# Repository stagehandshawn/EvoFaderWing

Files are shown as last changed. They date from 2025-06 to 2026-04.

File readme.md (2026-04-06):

# EvoFaderWing - [Wiki](https://github.com/stagehandshawn/EvoFaderWing/wiki)

<table width="100%">
  <tr>
    <td width="70%">
      <table width="100%">
        <tr>
          <td align="left">
            <strong>Author:</strong> ShawnR
          </td>
          <td align="right">
            <strong>Contact:</strong> <a href="mailto:stagehandshawn@gmail.com">stagehandshawn@gmail.com</a>
          </td>
        </tr>
      </table>
      <br>
      OSC control of grandMA3 faders with motorized feedback, backlit faders (follows appearances), 20 encoders, and 40 standard exec buttons.
      <br><br><blockquote>
        <strong>Note:</strong> This Guide is a work in progress but EvoFaderWing is fully functional. I continue to work on the repo as time permits.
      </blockquote>
    </td>
    <td width="30%" align="right" valign="top">
      faderwing
    </td>
  </tr>
</table>

[Bill Of Materials](https://github.com/stagehandshawn/EvoFaderWing/wiki/Bill-of-materials)

[Wiring Diagrams](https://github.com/stagehandshawn/EvoFaderWing/wiki/Wiring-Diagrams)

[Assembly](https://github.com/stagehandshawn/EvoFaderWing/wiki/Assembly)

I have added discussions to the repo so any questions can be asked there. 

## Features
### Same quantity of control surfaces as grandMA3 onPC Fader Wing
- 10 Motorized faders
  - Touch sensitive
  - LED backlit - follows appearances and brightens when touched
  - Self calibrated fader range and touch sensitivity
- 40 Executor keys (OSC or USB)
   - Can send keystrokes using OSC to execute actions only
   - USB allows you to apply actions (store, edit, etc.) using the hardware keys
- 20 Executor Encoders
- Web GUI

## Project Images

<table>
  <tr>
    <td width="50%">
      faderwing top
    </td>
    <td width="50%">
      faderwing right side
    </td>
  </tr>
  <tr>
    <td width="50%">
      faderwing back
    </td>
    <td width="50%">
      electronics bay
    </td>
  </tr>
</table>

**Watch the demo videos**

⏺ <table>
    <tr>
      <td width="30%">
Watch the demo video (https://www.youtube.com/watch?v=cR3AajQKoAo)
      </td>
      <td width="30%">
Watch the demo video (https://www.youtube.com/watch?v=fbl81pGS5f4)
      </td>
      <td width="30%">
Watch the demo video (https://www.youtube.com/watch?v=7ICJlkqCzxY)
      </td>
    </tr>
  </table>

## Required repositories

There are 3 repositories you will need to complete this build. This one is the main controller. The other two are:

- **EvoFaderWing_keyboard_i2c**
- **EvoFaderWing_encoder_i2c**

These run on ATmega328p MCUs and are I2C slaves for getting encoder data from 20 encoders (5 each on 4 ATmega328p's), and 1 ATmega for the keyboard matrix.

There is a Python script and a `tasks.json` for uploading code automatically for when the FaderWing is closed and you cannot get to the bootloader button.

## Required Lua

The Lua script `/lua/EvoFaderWingOSC.lua` will poll executors and send updates to the FaderWing using bundled OSC messages, and the FaderWing will send OSC back to the script.

- You will need to create 1 OSC connection
  - Name the Osc entry EvoFaderWing
  - Enter the IP Address of EvoFaderWing
  - Set Recieve and Send Command to Yes
  - Make sure to enter the IP Address of grandMA3 into the OSC settings of EvoFaderWing

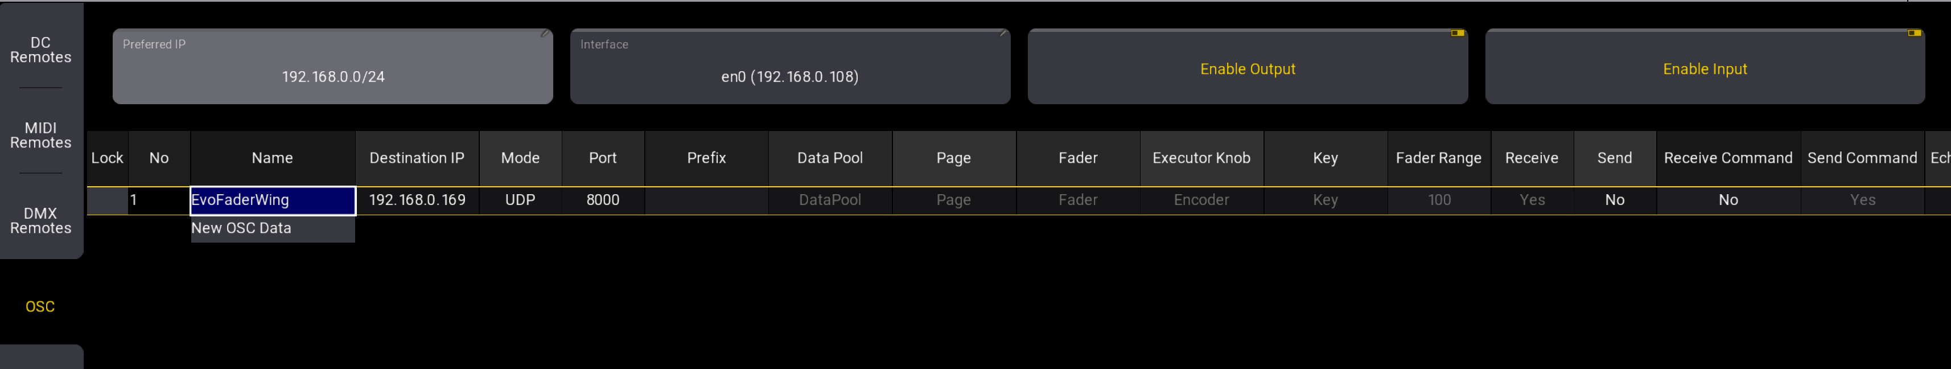
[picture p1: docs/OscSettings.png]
OscSettings


## Web GUI
- Network Setup

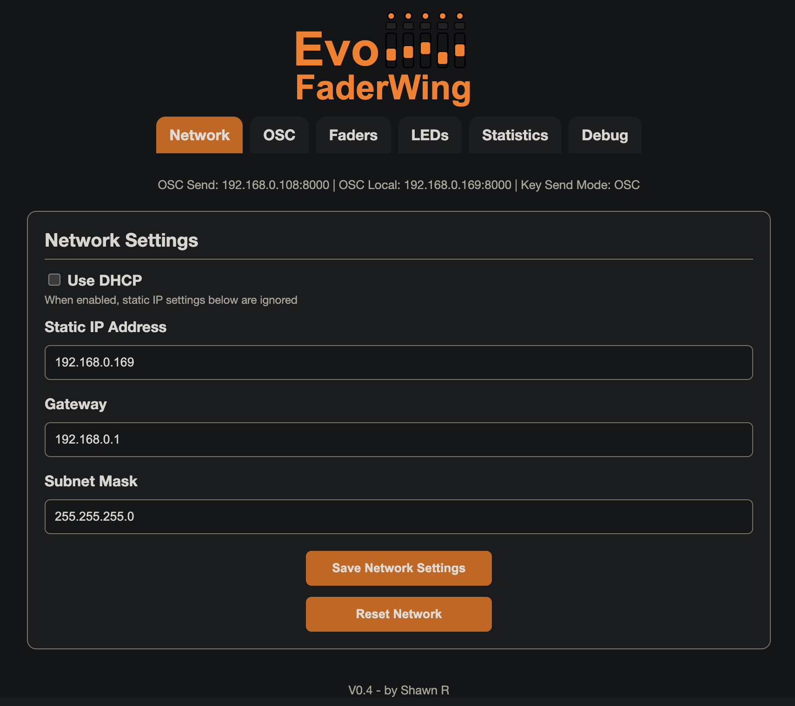
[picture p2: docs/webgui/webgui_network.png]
NetowrkSetup


- OSC Setup

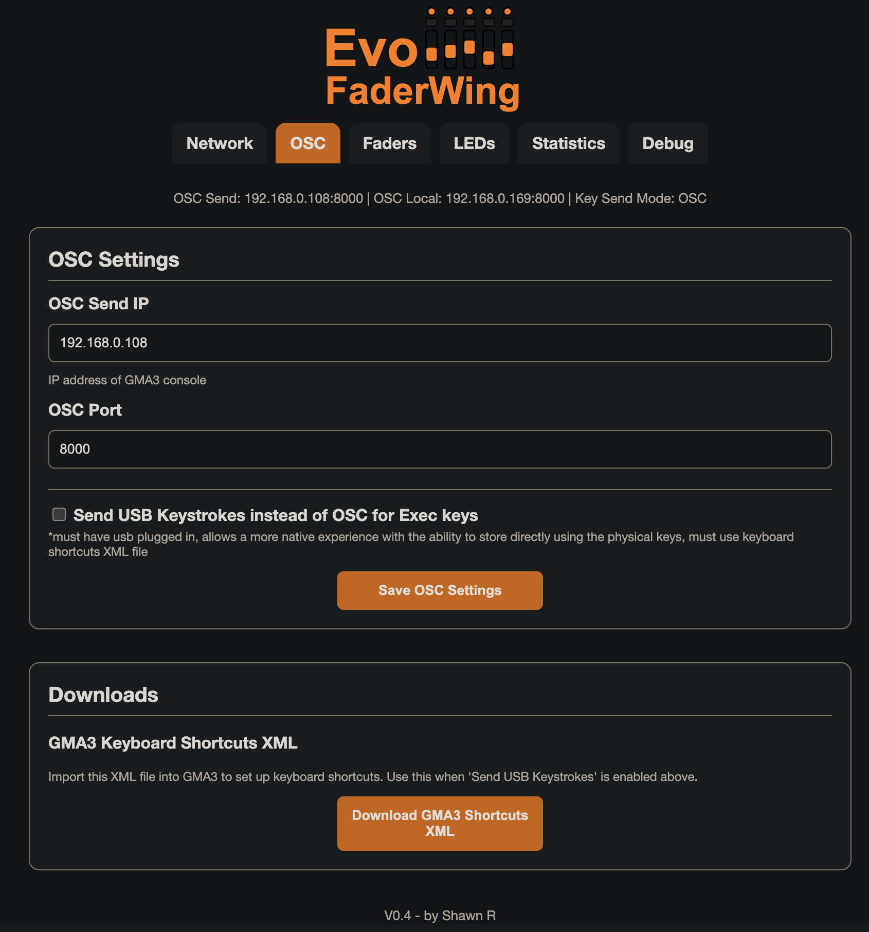
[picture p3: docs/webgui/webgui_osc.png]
OscSetup


- Faders

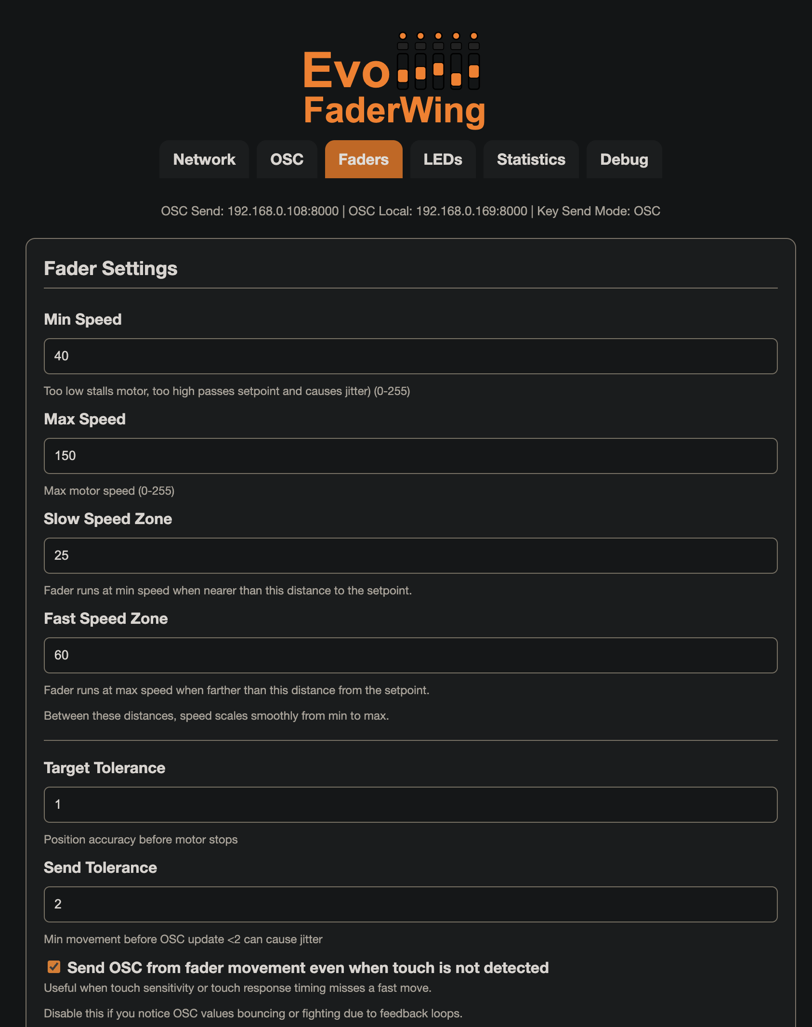
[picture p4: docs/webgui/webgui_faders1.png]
faders1


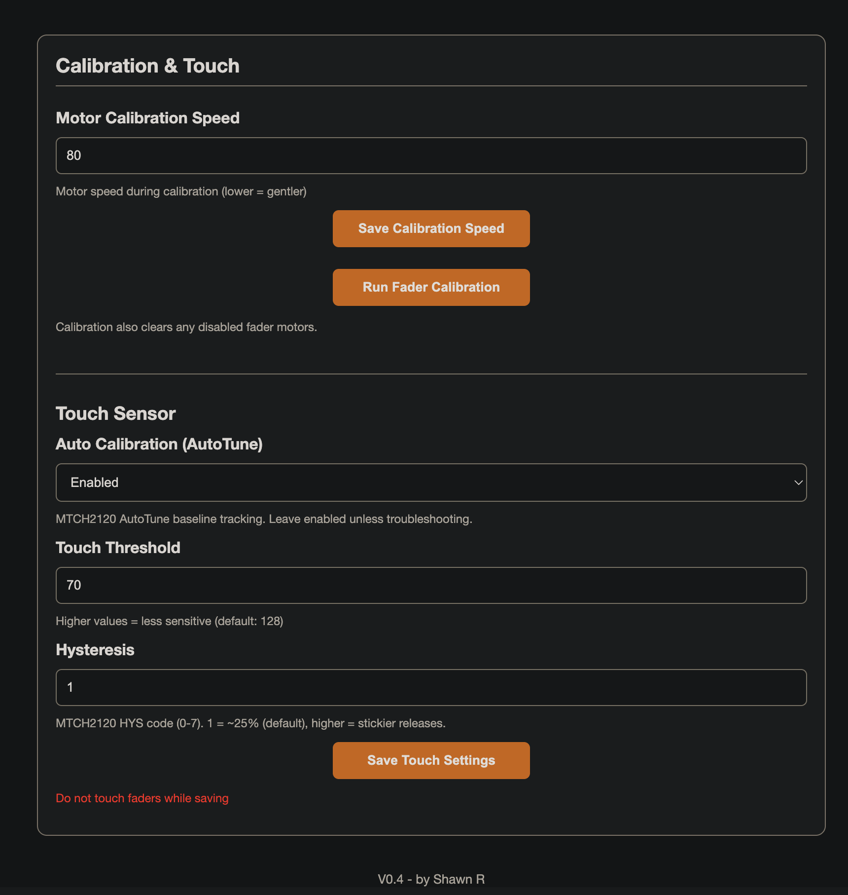
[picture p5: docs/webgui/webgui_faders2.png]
faders2


- Led Settings

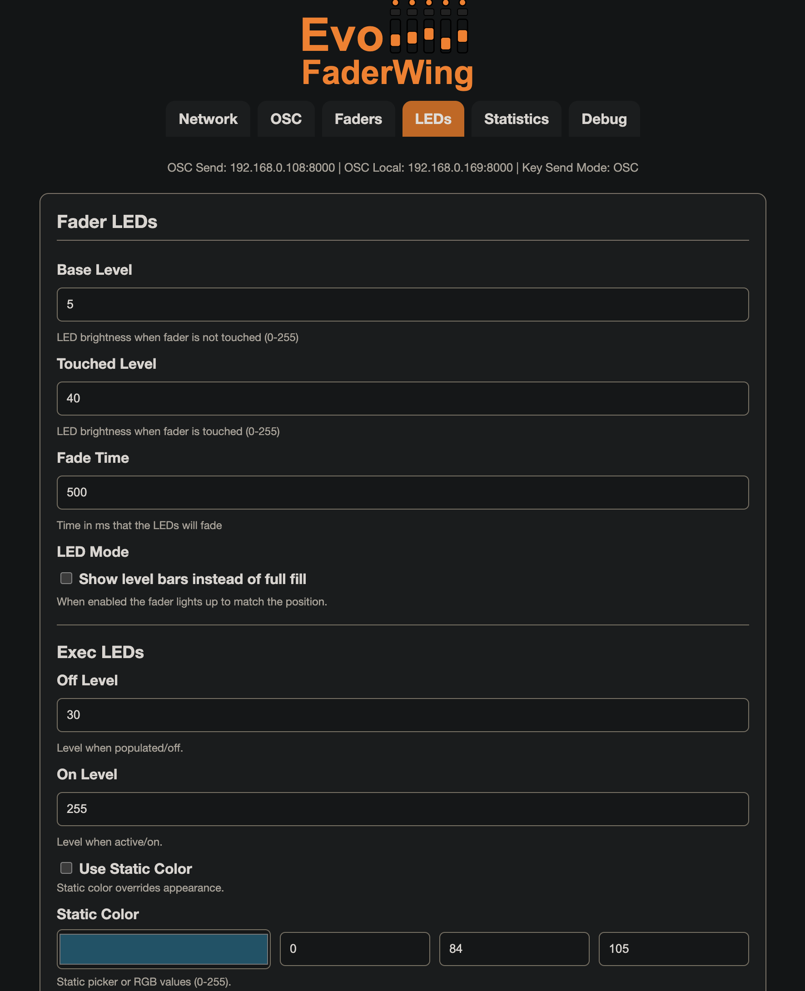
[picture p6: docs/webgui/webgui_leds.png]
leds


- Fader Stats

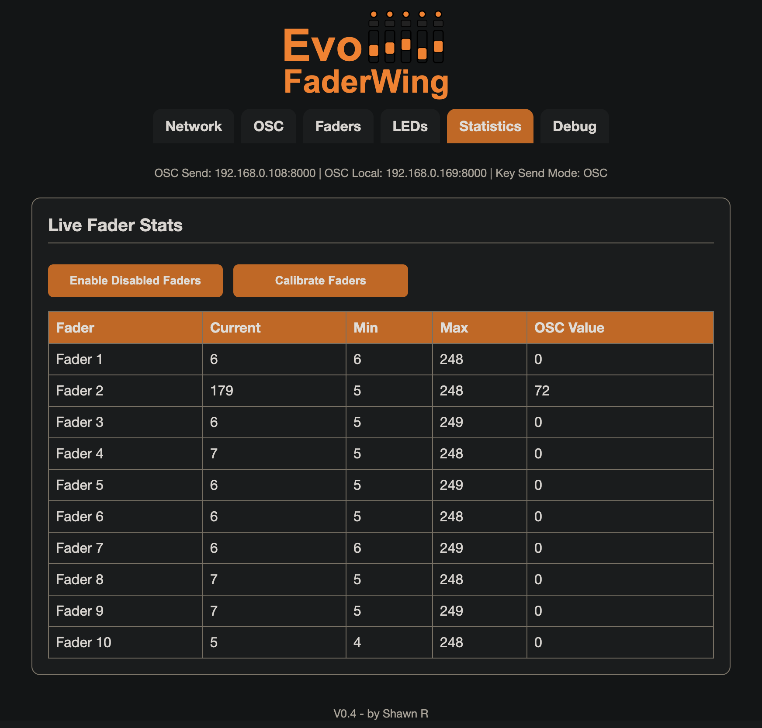
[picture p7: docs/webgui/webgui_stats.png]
stats


- Debug Settings

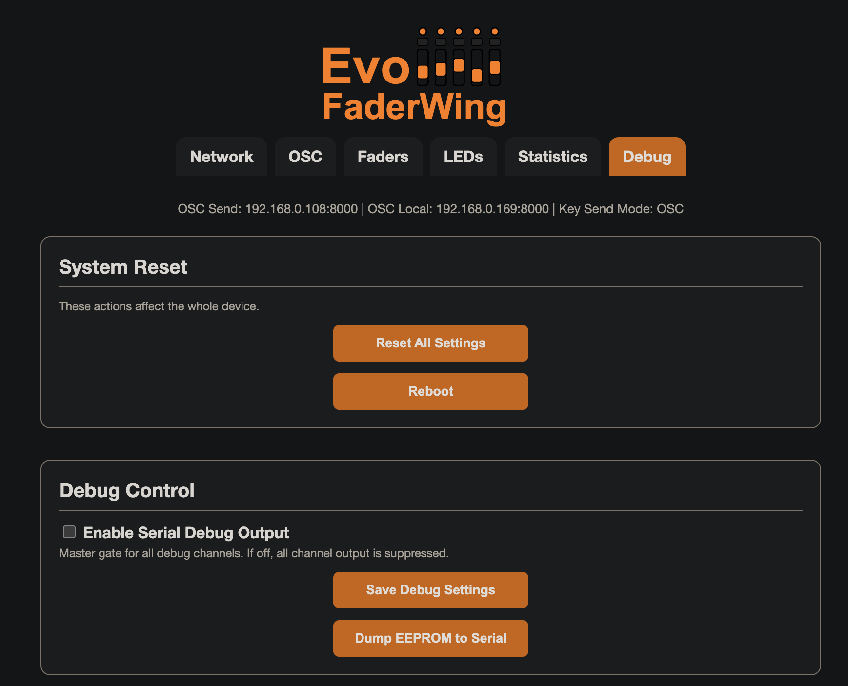
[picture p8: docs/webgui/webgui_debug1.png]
debug1


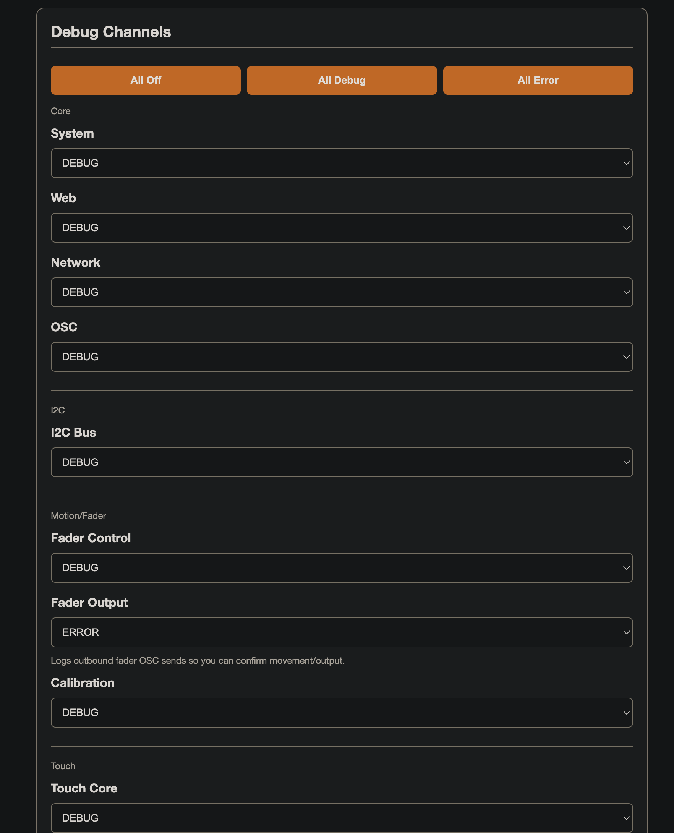
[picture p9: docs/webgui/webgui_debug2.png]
debug2


## For a complete setup add [EvoCmdWing](https://github.com/stagehandshawn/EvoCmdWing)
evocmdfaderwing

More to come. Thank you for checking out my project!

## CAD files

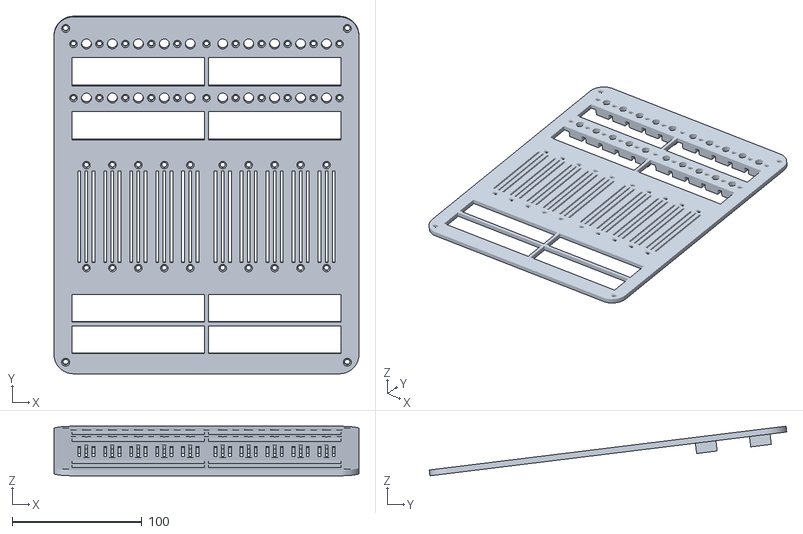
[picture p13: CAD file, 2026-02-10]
Cad_models/Top Plate_for_T-post_Faders.stl
235.0 x 275.5 x 38.2

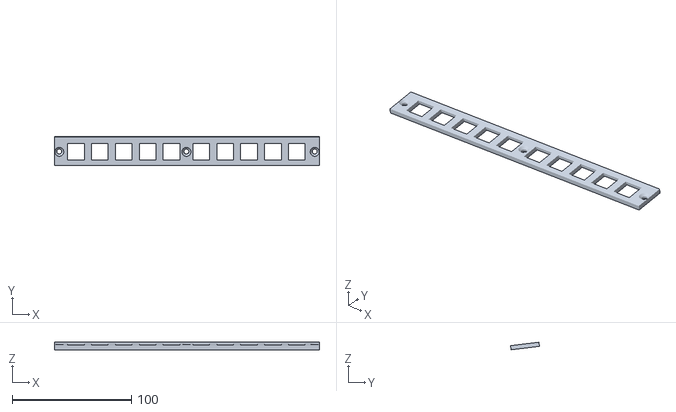
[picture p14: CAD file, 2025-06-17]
Cad_models/key_plate_top.stl
222.0 x 24.3 x 6.40

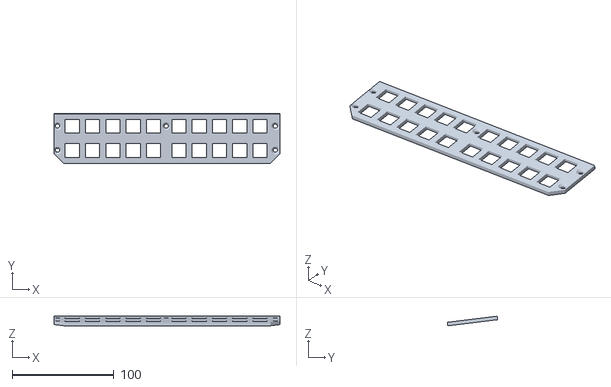
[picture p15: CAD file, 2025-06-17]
Cad_models/key_plate_bottom.stl
222.6 x 49.6 x 9.51

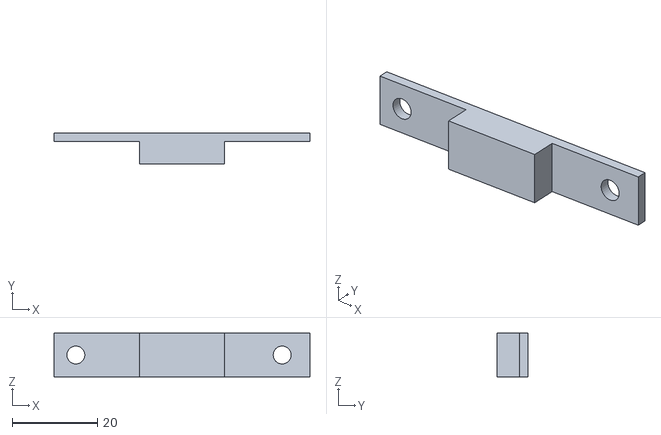
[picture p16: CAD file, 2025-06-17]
Cad_models/oled_bracket.stl
60.0 x 7.20 x 10.2

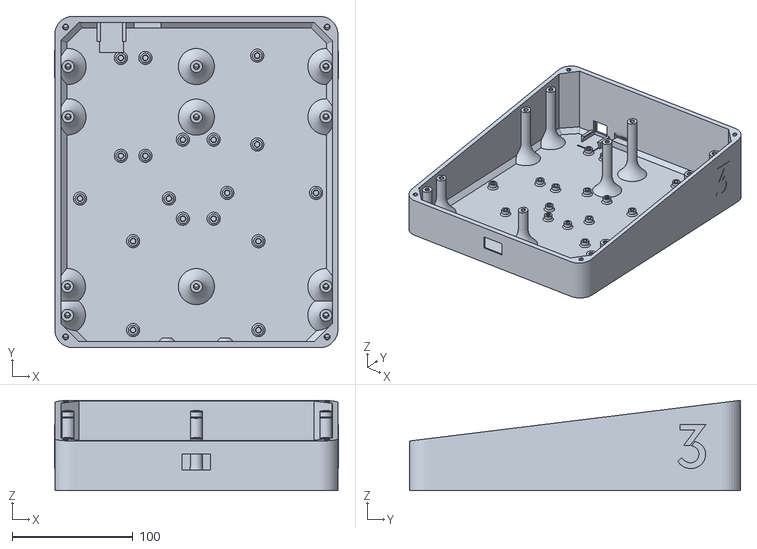
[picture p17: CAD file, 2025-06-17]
Cad_models/fader_base.stl
235.7 x 275.0 x 75.0

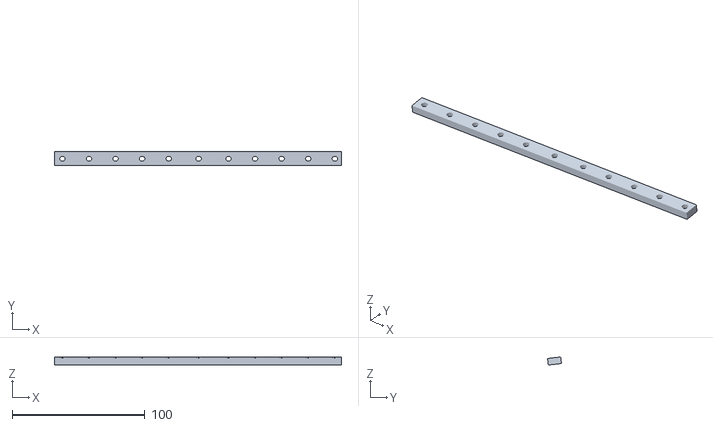
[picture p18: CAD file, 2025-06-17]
Cad_models/encoder_mount.stl
216.0 x 10.5 x 6.18

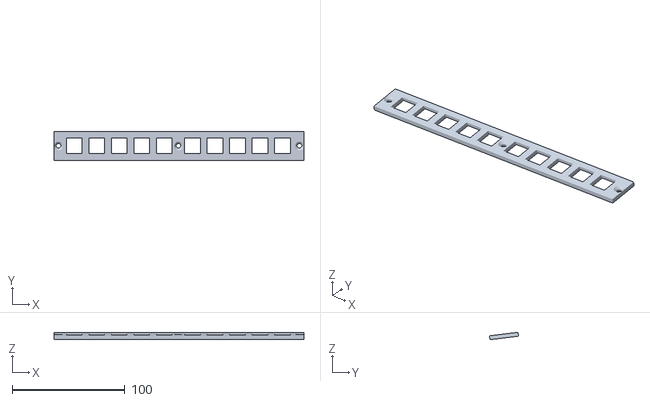
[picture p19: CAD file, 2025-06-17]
Cad_models/key_plate_mid.stl
222.0 x 25.7 x 6.58

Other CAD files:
Cad_models/Top Plate.stl
Cad_models/EvoFaderWing v1.f3d

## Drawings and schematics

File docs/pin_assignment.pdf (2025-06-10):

# Motor Fader Pin Assignment

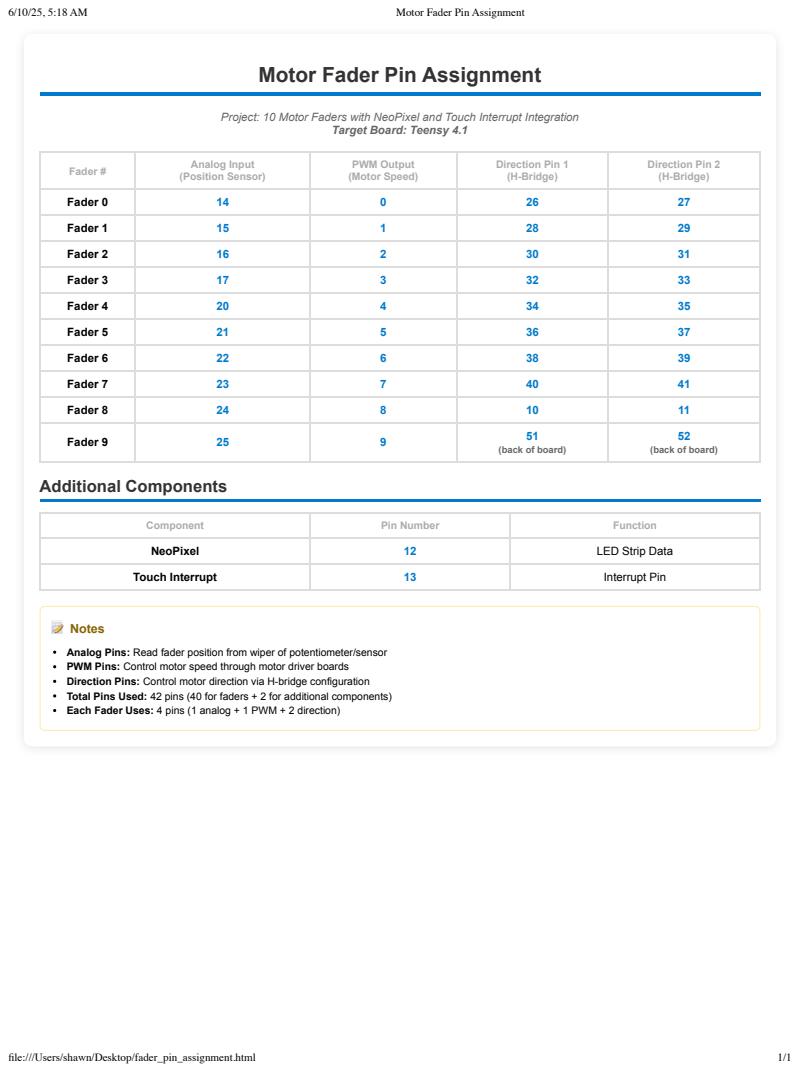
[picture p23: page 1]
Additional Components; 📝 Notes; Motor Fader Pin Assignment; file:///Users/shawn/Desktop/fader_pin_assignment.html

Project: 10 Motor Faders with NeoPixel and Touch Interrupt Integration

Target Board: Teensy 4.1

Fader # | Analog Input (Position Sensor) | PWM Output (Motor Speed) | Direction Pin 1 (H-Bridge) | Direction Pin 2 (H-Bridge)

Fader 0 | 14 | 0 | 26 | 27

Fader 1 | 15 | 1 | 28 | 29

Fader 2 | 16 | 2 | 30 | 31

Fader 3 | 17 | 3 | 32 | 33

Fader 4 | 20 | 4 | 34 | 35

Fader 5 | 21 | 5 | 36 | 37

Fader 6 | 22 | 6 | 38 | 39

Fader 7 | 23 | 7 | 40 | 41

Fader 8 | 24 | 8 | 10 | 11

Fader 9 | 25 | 9 | 51 (back of board) | 52 (back of board)

Component | Pin Number | Function

NeoPixel | 12 | LED Strip Data

Touch Interrupt | 13 | Interrupt Pin

Analog Pins: Read fader position from wiper of potentiometer/sensor
PWM Pins: Control motor speed through motor driver boards
Direction Pins: Control motor direction via H-bridge configuration
Total Pins Used: 42 pins (40 for faders + 2 for additional components)
Each Fader Uses: 4 pins (1 analog + 1 PWM + 2 direction)

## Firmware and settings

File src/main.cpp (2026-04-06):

// EvoFaderWing
// Main.cpp

// Teensy 4.1

#include <Arduino.h>
#include <QNEthernet.h>
#include <LiteOSCParser.h>

#include "Config.h"
#include "EEPROMStorage.h"
#include "TouchSensor.h"
#include "NetworkOSC.h"
#include "NetworkManager.h"
#include "FaderControl.h"
#include "NeoPixelControl.h"
#include "WebServer.h"
#include "Utils.h"
#include "i2cPolling.h"
#include "OLED.h"
#include "Keysend.h"
#include "KeyLedControl.h"

using namespace qindesign::network;
using qindesign::osc::LiteOSCParser;


unsigned long lastI2CPollTime = 0;     // Time of last I2C poll cycle

OLED display;             // define display 
//================================
// MAIN ARDUINO FUNCTIONS
//================================

void setup() {
  // Start the keyboard interface early so the USB device enumerates consistently on Windows
  initKeyboard();

  Serial.begin(SERIAL_BAUD);
  while (!Serial && millis() < 4000) {}
  
  SYSTEM_DEBUG_PRINT("EvoFaderWing init...");

  // Initialize faders
  initializeFaders();
  configureFaderPins();
  
  // Initialize touch sensor (MTCH2120)
  if (!setupTouch()) {
    TOUCH_ERROR_PRINT("Touch sensor init failed!");
  }

  // Start NeoPixels
  setupNeoPixels();
  setupKeyLeds();

    // Check calibration will load calibration data if present ortherwise it will run calibration
  checkCalibration(); 

  // Load configurations from EEPROM
  loadAllConfig();

  moveAllFadersToSetpoints();
  // Calibrate touch sensor once faders are parked at center
  runTouchCalibration();

  //Setup I2C Slaves so we can also check for network reset
  setupI2cPolling();
  
  // Setup OLED before network to watch for no dhcp server and know were booting
  display.setupOLED();

  // Set up network manager and network-facing services
  initNetworkManager();

  // Start web server for configuration
  startWebServer();

  fadeSequence(50,1000); // Startup indication after initialization completes

  //Network reset check
  resetCheckStartTime = millis();

  SYSTEM_DEBUG_PRINT("Initialization complete");

}

void loop() {
  Ethernet.loop();

  static unsigned long lastNetworkServiceMs = 0;
  const unsigned long now = millis();
  const unsigned long networkServiceIntervalMs = networkIsConnected() ? 100UL : 50UL;
  if (now - lastNetworkServiceMs >= networkServiceIntervalMs) {
    lastNetworkServiceMs = now;
    serviceNetwork();
  }

  // Network reset check exiry PRESS 401 5 times during this time for network reset

  if (checkForReset && (millis() - resetCheckStartTime > 5000)) {
    checkForReset = false;
    SYSTEM_DEBUG_PRINT("[RESET] Reset check window expired.");
  }
  
  checkFaderRetry();  // Check for hung fader

  // Check for manual fader movement
  handleFaders();

  // Handle I2C Polling for encoders keypresses and encoder key press
  handleI2c();

  // Process queued OSC packets from UDP callback
  processOscQueue();
  
    
  // Process touch changes 
  if (processTouchChanges()) { updateBrightnessOnFaderTouchChange(); }

  // Check for web requests
  pollWebServer();
  

  // Handle touch sensor errors, no longer needed used for debugging
  if (hasTouchError()) {
    TOUCH_ERROR_PRINT(getLastTouchError().c_str());
    clearTouchError();
  }
  
    // Update NeoPixels
  updateNeoPixels();
  updateKeyLeds();

  // Check for reboot from serial, used for uploading firmware without having to press physical button
  checkSerialForReboot();

}


// oled display functions

void displayIPAddress(){
  display.showIPAddress(networkGetLocalIP(), netConfig.oscPort, netConfig.sendToIP);
}

void displayShowResetHeader(){
  display.clear();
  display.showHeader("Network Reset");
}

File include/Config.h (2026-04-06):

// Config.h
#ifndef CONFIG_H
#define CONFIG_H

#include <Arduino.h>
#include <IPAddress.h>

//================================
// IDENTITY
//================================
#define PROJECT_NAME "EvoFaderWing"
#define SW_VERSION      "0.4"

//================================
// DEBUG CHANNELS
//================================
enum DebugLevel : uint8_t {
  DBG_OFF = 0,
  DBG_ERROR = 1,
  DBG_DEBUG = 2
};

enum DebugChannel : uint8_t {
  DBG_CH_SYSTEM = 0,
  DBG_CH_WEB,
  DBG_CH_NETWORK,
  DBG_CH_OSC,
  DBG_CH_I2C_BUS,
  DBG_CH_FADER_CORE,
  DBG_CH_FADER_POSITION,
  DBG_CH_TOUCH_CORE,
  DBG_CH_TOUCH_RAW,
  DBG_CH_CALIBRATION,
  DBG_CH_EEPROM,
  DBG_CH_LED_EXEC,
  DBG_CH_OLED,
  DBG_CH_COUNT
};

static const uint8_t DEBUG_CHANNEL_COUNT = (uint8_t)DBG_CH_COUNT;
static const uint8_t DEBUG_CONFIG_VERSION = 2;

//================================
// HARDWARE CONFIGURATION
//================================

// Fader configuration
#define NUM_FADERS      10       // Total number of motorized faders
#define SERIAL_BAUD     115200   // Baud rate for USB serial output/debug

// Motor control defaults tuned for a 12V PSU; adjust if the hardware uses a lower supply voltage.
#define MAX_PWM        150      // Default motor speed (PWM duty cycle) during normal operation (0–255) BEST at 100-150
#define CALIB_PWM       80       // Reduced motor speed during auto-calibration phase
#define MIN_PWM         40       // Minimum PWM to overcome motor inertia 
#define PWM_FREQ     25000      // Frequency of the motors PWM output 25khz
#define FADER_MOVE_TIMEOUT     2000   // Time in MS a fader must not be moving before force stopped
#define RETRY_INTERVAL         1000    // How long before trying to move a stuck fader
#define FADER_MAX_FAILURES       3     // Consecutive timeouts before disabling a fader motor

// Fader position tolerances
#define TARGET_TOLERANCE 1       // OSC VALUE How close the fader must be to setpoint to consider "done"
#define SEND_TOLERANCE   2       // Amout of change in OSC (0-100) before senind an osc update
#define ANALOG_NOISE_TOLERANCE 1 // Suppress tiny ADC jitter (counts) before mapping to OSC (current default set for 8bit reads)
#define SLOW_ZONE        25      // OSC units - start slowing earlier for smoother approach
#define FAST_ZONE        60      // OSC units - when to use full speed

// Calibration settings
#define PLATEAU_THRESH   2       // Threshold (analog delta) to consider that the fader has stopped moving
#define PLATEAU_COUNT    10      // How many stable readings in a row needed to "lock in" max or min during calibration


// OSC settings
#define OSC_VALUE_THRESHOLD 2    // Minimum value change to send OSC update
#define OSC_RATE_LIMIT     20    // Minimum ms between OSC messages

// NeoPixel configuration
#define NEOPIXEL_PIN 12
#define PIXELS_PER_FADER 24
#define NUM_PIXELS (NUM_FADERS * PIXELS_PER_FADER)

// Executor key NeoPixel strip (40 keys, 2 pixels each)
#define NUM_EXECUTORS_TRACKED 40
#define EXECUTOR_PIXELS_PER_KEY 2
#define EXECUTOR_LED_PIN 53   // Teensy 4.1 pin for the key strip
#define EXECUTOR_LED_COUNT (NUM_EXECUTORS_TRACKED * EXECUTOR_PIXELS_PER_KEY)
#define EXECUTOR_BASE_BRIGHTNESS 10   // Default base brightness for populated-but-off keys
#define EXECUTOR_ACTIVE_BRIGHTNESS 80 // Default brightness for active/on keys (unpopulated stays dark)

// Touch sensor configuration
#if defined(TOUCH_SENSOR_MTCH2120) && defined(TOUCH_SENSOR_MPR121)
#error "Select only one touch sensor: TOUCH_SENSOR_MTCH2120 or TOUCH_SENSOR_MPR121"
#endif

// Default to MTCH2120
#if !defined(TOUCH_SENSOR_MTCH2120) && !defined(TOUCH_SENSOR_MPR121)
#define TOUCH_SENSOR_MTCH2120 1
#endif

#define IRQ_PIN 41

#ifndef MTCH2120_ADDRESS
#define MTCH2120_ADDRESS 0x20
#endif

#ifndef MPR121_ADDRESS
#define MPR121_ADDRESS 0x5A
#endif

//================================
// PIN ASSIGNMENTS
//================================

// Analog input pins for fader position
extern const uint8_t ANALOG_PINS[NUM_FADERS];

// PWM output pins for motor speed
extern const uint8_t PWM_PINS[NUM_FADERS];

// Direction control pins for motors
extern const uint8_t DIR_PINS1[NUM_FADERS];
extern const uint8_t DIR_PINS2[NUM_FADERS];

// OSC IDs for each fader
extern const uint16_t OSC_IDS[NUM_FADERS];

//================================
// BRIGHTNESS SETTINGS
//================================


//================================
// NETWORK CONFIGURATION
//================================
constexpr uint32_t kDHCPTimeout = 15000;  // Timeout for DHCP in milliseconds
constexpr uint16_t kOSCPort = 8000;       // Default OSC port
constexpr char kServiceName[] = "evofaderwing"; // mDNS service name and Hostname
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

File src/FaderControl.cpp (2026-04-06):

// FaderControl.cpp
#include "FaderControl.h"
#include "NetworkOSC.h"
#include "TouchSensor.h"
#include "WebServer.h"
#include "Utils.h"
#include "NeoPixelControl.h"

bool FaderRetryPending = false;
unsigned long FaderRetryTime = 0;
static bool FaderMoveActive = false;
static const uint8_t MANUAL_DETECT_DELTA = 1;
static const unsigned long MANUAL_OVERRIDE_HOLD_MS = 500;
static const unsigned long REMOTE_CONTROL_LOCKOUT_MS = 800;

static inline bool allowFaderOscWithoutTouchMode() {
  return Fconfig.allowFaderOscWithoutTouch;
}

//================================
// MOTOR CONTROL
//================================


void driveMotorWithPWM(Fader& f, int direction, int pwmValue) {
  if (!f.motorEnabled) {
    // Keep motor off when disabled
    digitalWrite(f.dirPin1, LOW);
    digitalWrite(f.dirPin2, LOW);
    analogWrite(f.pwmPin, 0);
    return;
  }

  if (direction == 0) {
    // Stop the motor
    digitalWrite(f.dirPin1, LOW);
    digitalWrite(f.dirPin2, LOW);
    analogWrite(f.pwmPin, 0);
    return;
  }
  
  // Set direction pins
  if (direction > 0) {
    // Move up/forward
    digitalWrite(f.dirPin1, HIGH);
    digitalWrite(f.dirPin2, LOW);
  } else {
    // Move down/backward
    digitalWrite(f.dirPin1, LOW);
    digitalWrite(f.dirPin2, HIGH);
  }
  
  // Apply custom PWM speed
  analogWrite(f.pwmPin, pwmValue);
}

int calculateVelocityPWM(int difference) {
  int absDifference = abs(difference);
  
  // Define PWM ranges
  const int minPWM = Fconfig.minPwm;   // Minimum PWM to ensure movement (adjust as needed)
  const int maxPWM = Fconfig.maxPwm;  // Use the configured maximum PWM
  
  // Define distance thresholds for different speeds
  int slowZone = Fconfig.slowZone;   // OSC units - start slowing earlier for smoother approach
  int fastZone = Fconfig.fastZone;   // OSC units - when to use full speed
  // Guard against invalid values (OSC is 0-100)
  if (slowZone < 0) slowZone = 0;
  if (fastZone < 0) fastZone = 0;
  if (slowZone > 100) slowZone = 100;
  if (fastZone > 100) fastZone = 100;
  if (fastZone <= slowZone) {
    slowZone = SLOW_ZONE;
    fastZone = FAST_ZONE;
  }
  
  
  int pwmValue;
  
  if (absDifference >= fastZone) {
    // Far from target - use full speed
    pwmValue = maxPWM;
  } else if (absDifference <= slowZone) {
    // Close to target - use minimum speed
    pwmValue = minPWM;
  } else {
    // In between - linear interpolation
    float ratio = (float)(absDifference - slowZone) / (fastZone - slowZone);
    pwmValue = minPWM + (int)(ratio * (maxPWM - minPWM));
  }
  
  return pwmValue;
}


//================================
// MOVE ALL FADERs TO SETPOINT
//================================

void moveAllFadersToSetpoints() {
  if (FaderMoveActive) {
    // Already running; let the current pass finish using updated setpoints
    return;
  }
  FaderMoveActive = true;

  bool allFadersAtTarget = false;
  unsigned long moveStartTime = millis();

  while (!allFadersAtTarget) {
    allFadersAtTarget = true; // Assume all are at target until proven otherwise
    

    for (int i = 0; i < NUM_FADERS; i++) {
      Fader& f = faders[i];

      if (!f.motorEnabled) {
        // Disabled motors are treated as parked; ensure power is off
        driveMotorWithPWM(f, 0, 0);
        continue;
      }
      
      // Read current position as OSC value
      int currentOscValue = readFadertoOSC(f);
      
      
      // Calculate difference in OSC units
      int difference = f.setpoint - currentOscValue;
      
      // Check if we need to move this fader (using a smaller tolerance for OSC units) IF NOT TOUCHING IT
      bool manualOwnershipActive = allowFaderOscWithoutTouchMode() && f.manualOverride;
      if (abs(difference) > Fconfig.targetTolerance && !f.touched && !manualOwnershipActive) {
        allFadersAtTarget = false; // At least one fader is not at target
        
        if (difference > 0) {
          // Need to move up
          int pwm = calculateVelocityPWM(difference);
          driveMotorWithPWM(f, 1, pwm);
        } else {
          // Need to move down  
          int pwm = calculateVelocityPWM(difference);
          driveMotorWithPWM(f, -1, pwm);
        }

        } else {
          // Fader is at target, stop motor
          driveMotorWithPWM(f, 0, 0);
        }

    }
    
    // Yield to prevent overwhelming the system
    yield();
    
    // Add timeout protection to prevent infinite loops

    if (millis() - moveStartTime > FADER_MOVE_TIMEOUT) {
      // Stop all motors and flash red on faders that didn't reach target
      bool failed[NUM_FADERS] = {false};
      bool retryNeeded = false;
      uint8_t origColors[NUM_FADERS][3] = {{0}};
      uint8_t scaledRed = (uint8_t)((255UL * Fconfig.touchedBrightness) / 255UL);

      for (int i = 0; i < NUM_FADERS; i++) {
        Fader& f = faders[i];
        driveMotorWithPWM(f, 0, 0);

        if (!f.motorEnabled) {
          continue;
        }

        int currentOscValue = readFadertoOSC(f);
        int difference = f.setpoint - currentOscValue;
        bool manualOwnershipActive = allowFaderOscWithoutTouchMode() && f.manualOverride;
        if (abs(difference) > Fconfig.targetTolerance && !f.touched && !manualOwnershipActive) {
          failed[i] = true;
          origColors[i][0] = f.red;
          origColors[i][1] = f.green;
          origColors[i][2] = f.blue;
        }
      }

      // Flash all failed faders together (full strip red) without using
      for (int flash = 0; flash < 3; flash++) {
        for (int i = 0; i < NUM_FADERS; i++) {
          if (!failed[i]) continue;
          for (int j = 0; j < PIXELS_PER_FADER; j++) {
            pixels.setPixelColor(i * PIXELS_PER_FADER + j, pixels.Color(scaledRed, 0, 0));
          }
        }
        pixels.show();
        delay(150);

        for (int i = 0; i < NUM_FADERS; i++) {
          if (!failed[i]) continue;
          for (int j = 0; j < PIXELS_PER_FADER; j++) {
            pixels.setPixelColor(i * PIXELS_PER_FADER + j, pixels.Color(origColors[i][0], origColors[i][1], origColors[i][2]));
          }
        }
        pixels.show();
        delay(50);
      }
      
      // Track failures and disable motors that repeatedly time out
      unsigned long failureTime = millis();
      for (int i = 0; i < NUM_FADERS; i++) {
        if (!failed[i]) {
          continue;
        }

        Fader& f = faders[i];
        f.failureCount++;
        f.lastFailureTime = failureTime;
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

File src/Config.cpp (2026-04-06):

// Config.cpp
#include "Config.h"

static const uint8_t kDefaultDebugLevels[DEBUG_CHANNEL_COUNT] = {
  DBG_ERROR, // SYSTEM
  DBG_ERROR, // WEB
  DBG_ERROR, // NETWORK
  DBG_ERROR, // OSC
  DBG_ERROR, // I2C_BUS
  DBG_ERROR, // FADER_CORE
  DBG_OFF,   // FADER_POSITION
  DBG_ERROR, // TOUCH_CORE
  DBG_OFF,   // TOUCH_RAW
  DBG_ERROR, // CALIBRATION
  DBG_ERROR, // EEPROM
  DBG_ERROR, // LED_EXEC
  DBG_ERROR  // OLED
};

//================================
// MAIN FADER ARRAY
//================================
// Holds runtime data for each motorized fader.
// This is the primary data structure manipulated by control logic.
Fader faders[NUM_FADERS];

//================================
// PIN CONFIGURATION ARRAYS
//================================
// Analog input pins connected to fader position sensors (wipers).
const uint8_t ANALOG_PINS[NUM_FADERS] = {14, 15, 16, 17, 20, 21, 22, 23, 24, 25};

// PWM output pins used to control fader motor speed via motor drivers.
const uint8_t PWM_PINS[NUM_FADERS] = {0, 1, 2, 3, 4, 5, 6, 7, 8, 9};

//USE 12 for NEOPIXEL
//USE 41 for MRP121/MTCH2120 IRQ
//USE 18 (SDA), 19(SCL) for I2C

// Motor direction control pins — each fader has two pins for H-bridge control.
const uint8_t DIR_PINS1[NUM_FADERS] = {26, 28, 30, 32, 34, 36, 38, 40, 10, 51};
const uint8_t DIR_PINS2[NUM_FADERS] = {27, 29, 31, 33, 35, 37, 39, 13, 11, 52};

// Unique OSC IDs for each fader (used to construct OSC address strings).
const uint16_t OSC_IDS[NUM_FADERS] = {201, 202, 203, 204, 205, 206, 207, 208, 209, 210};

//================================
// FADER BEHAVIOR CONFIGURATION
//================================
// Default PID and motor tuning settings shared across all faders.
FaderConfig Fconfig = {
  .minPwm = MIN_PWM,
  .maxPwm = MAX_PWM,
  .calibratePwm = CALIB_PWM,
  .targetTolerance = TARGET_TOLERANCE,
  .sendTolerance = SEND_TOLERANCE,
  .slowZone = SLOW_ZONE,
  .fastZone = FAST_ZONE,
  .baseBrightness = 5,
  .touchedBrightness = 40,
  .fadeTime = 500,
  .serialDebug = debugMode,
  .sendKeystrokes = false,
  .useLevelPixels = false,
  .allowFaderOscWithoutTouch = true,
  .debugConfigVersion = DEBUG_CONFIG_VERSION,
  .debugLevel = {
    DBG_ERROR, // SYSTEM
    DBG_ERROR, // WEB
    DBG_ERROR, // NETWORK
    DBG_ERROR, // OSC
    DBG_ERROR, // I2C_BUS
    DBG_ERROR, // FADER_CORE
    DBG_OFF,   // FADER_POSITION
    DBG_ERROR, // TOUCH_CORE
    DBG_OFF,   // TOUCH_RAW
    DBG_ERROR, // CALIBRATION
    DBG_ERROR, // EEPROM
    DBG_ERROR, // LED_EXEC
    DBG_ERROR  // OLED
  }
};

// Executor LED defaults
ExecConfig execConfig = {
  .baseBrightness = EXECUTOR_BASE_BRIGHTNESS,
  .activeBrightness = EXECUTOR_ACTIVE_BRIGHTNESS,
  .useStaticColor = false,
  .staticRed = 255,
  .staticGreen = 255,
  .staticBlue = 255,
  .reserved = {0, 0}
};

//================================
// NETWORK CONFIGURATION
//================================
// Default static network settings and UDP destination info.
// These values can be updated at runtime or overridden via web UI.
NetworkConfig netConfig = {
  IPAddress(192, 168, 0, 169),     // staticIP
  IPAddress(192, 168, 0, 1),       // gateway
  IPAddress(255, 255, 255, 0),     // subnet
  IPAddress(192, 168, 0, 10),     // sendToIP (OSC target)
  kOSCPort,                        // oscPort (shared OSC send/receive)
  true                             // useDHCP (fallback to static if false)
};

// Network reset check
bool checkForReset = true;
unsigned long resetCheckStartTime = 0;

// Calibration state flag
bool calibrationInProgress = false;


//================================
// DEBUG SETTINGS
//================================
#ifdef DEBUG
  bool debugMode = true;  // Enables or disables verbose serial output
#else
  bool debugMode = false;  // Enables or disables verbose serial output
#endif

//================================
// TOUCH SENSOR GLOBALS
//================================
// These are used by the touch driver and web UI configuration.
int autoCalibrationMode = 1;      // 0 = AutoTune off, 1 = AutoTune on
#if defined(TOUCH_SENSOR_MTCH2120)
uint8_t touchThreshold = 128;     // Higher = less sensitive (MTCH2120 per-key threshold)
uint8_t releaseThreshold = 1;     // Hysteresis code 0-7
#else
uint8_t touchThreshold = 12;      // Higher = less sensitive (MPR121 default)
uint8_t releaseThreshold = 6;     // Lower = harder to release (MPR121 default)
#endif


// Page Tracking
int currentOSCPage = 1;  // Default to page 1

void loadDefaultDebugLevels(uint8_t* levels, size_t count) {
  if (levels == nullptr || count == 0) {
    return;
  }

  size_t maxCount = count;
  if (maxCount > DEBUG_CHANNEL_COUNT) {
    maxCount = DEBUG_CHANNEL_COUNT;
  }

  for (size_t i = 0; i < maxCount; ++i) {
    levels[i] = kDefaultDebugLevels[i];
  }
}
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

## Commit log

2025-05-22 GMA3 Fader wing v4 ported to platformio
2025-05-23 added i2c polling master code, have not applied it to main.cpp yet
2025-05-30 Fix I2C keyboard slave with circular buffer and interrupt protection
    [EEPROMStorage.cpp, EEPROMStorage.h, NeoPixelControl.cpp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]
2025-06-09 chagned calibrate timeout, working on auto upload.py
2025-06-09 fixed fader calibration saves, and web gui, have not changed fadercontrol yet, this is the save point before that
    [EEPROMStorage.cpp, FaderControl.cpp, main.cpp]
2025-06-10 added support for all black led color in hsv scaling
2025-06-12 Finally getting the faders fixed we are getting closer
    [Config.cpp, Config.h, EEPROMStorage.h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]
2025-06-12 Faders working well no PID, missing some osc messages, need to update lua script or add multi tasking in teensy code
    [main.cpp]
2025-06-12 added clamping to top and bottom of analog fader reads for true 0-100 moves
2025-06-12 Working keypress send and encoder sends, also faders are working well, may need pid later
2025-06-12 Good working order with vel scaling, need to clean code, and fix web gui and eeprom saves crashing
    [Config.cpp, Config.h, FaderControl.cpp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]
2025-06-12 fixed up the web gui and cleaned out unsused functions and variables like PID stuff
    [Config.cpp, Config.h, EEPROMStorage.cpp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]
2025-06-13 Fixed webgui a lot and save settings works better now, update leds on base change
    [EEPROMStorage.cpp, NeoPixelControl.cpp, OLED.cpp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]
2025-06-13 fixed not sending osc at top and bottom with fast moves, added forceflag to bypass rate limiting
    [FaderControl.cpp, OLED.cpp, OLED.h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]
2025-06-13 removed deadzone and changed to minimum pwm, still need to fix web gui text and saving of debug settings
    [Config.cpp, Config.h, EEPROMStorage.cpp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]
2025-06-13 added debug to saved data in fconfig struct, still need to fix some text in webgui
    [Config.cpp, Config.h, EEPROMStorage.cpp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]
2025-06-15 added updated lua script with correct print output
    [Config.h, WebServer.cpp, i2cPolling.cpp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]
2025-06-17 added readme, images, and cad models
    [EvoFaderWing v1.f3d, Top Plate.stl, encoder_mount.stl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]
2025-06-17 modified led channels in top_plate to be deeper
    [EvoFaderWing v1.f3d, Top Plate.stl]
2025-06-17 Desabled serial debug by default IT WILL CAUSE JITTER ONLY USE WHEN DEBUGGING
2025-06-18 adding wiring diagrams
2025-06-18 readme update to include wiring diagrams
2025-06-19 added keyboard matrix wiring guide
2025-06-20 adding top plate wiring diagrams
2026-02-10 Added New top plate to fit T post faders ALPS RS60N11M9AOF
    [Top Plate_for_T-post_Faders.stl]
2026-03-28 Modified executor 305 keybaord shortcut to use the equal key to allow commandwing to use 't' for thru button
    [WebServer.cpp]
